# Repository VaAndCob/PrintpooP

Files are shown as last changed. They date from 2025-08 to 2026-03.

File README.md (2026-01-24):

# PrintpooP – Retro Pixel Smart Display for Bambu Lab A1

- WORK BOTH 2.4" and 2.8" Resistive Touch Screen
- Firmware version: display on the top left-most on the welcome screen
- [Version history](https://github.com/VaAndCob/PrintpooP/blob/main/CHANGELOG.md)
## Quick start, flash and go, no code needed
- [Flash Firmware Online for 2.4" and 2.8"](https://vaandcob.github.io/webpage/src/index.html)
--------------------------  
🎬[Watch on Youtube](https://www.youtube.com/playlist?list=PLtzfxJvwUDCUxc5Is3-2UeWByNE8M8oDE)

PrintpooP

Introduction: This doesn’t make my prints any better… but it does make my printer look way cooler 😂

A compact, ESP32-powered accessory designed specifically for the Bambu Lab A1, A1 Mini 3D printer. It replaces the original hotend faceplate with a custom 3D-printed enclosure (the "Box") that houses a vibrant 2.4" touchscreen display.

📡 Live Status Display
PrintpooP connects to your A1 via Wi-Fi and presents real-time print data, such as print progress, temperatures, fan speeds, and Clock. Right at the print head. This localised status view makes monitoring more intuitive and visually engaging.

🎮 8-Bit Aesthetic
All visuals are styled in charming 8-bit pixel art, giving your printer a retro personality. Animations and icons are custom-designed to blend nostalgic design with functional UX and sound effects.
Choose between two adorable themes: a playful **Kitten** or a loyal **Puppy** to accompany your printing journey!
🛠️ Easy Mounting
The enclosure is engineered to replace the Bambu Lab A1's default hotend faceplate, securing PrintpooP in a clean, integrated form factor.

HOW TO USE: 
1. Touch screen calibration will be displayed during the first run, but can also be manually entered by pressing the RESET button and releasing, then pressing the BOOT (GPIO_0) button within one second and holding it for a second.
Use a touch pen to touch all 4 corners of the screen.
2. SETUP → Wi-Fi Tab to configure Wi-Fi credentials.
3. SETUP → Printer Tab to configure the printer's IP address, access code, serial number, and time zone.
4. Enter the printer's IP address, access code, serial number, and time zone on the SETUP → Printer Tab
   
    How to get printer serial number:  https://wiki.bambulab.com/en/general/find-sn
   
    How to get printer IP address & Access Code:  https://wiki.bambulab.com/en/software/bambu-studio/failed-to-send-print-files
5. Currently, there are 4 status display pages
   
   Page 1 - PrintpooP in action (displays a cute kitten or puppy for each print stage)

      - After one minute of inactivity, trigger a "PrintpooP" swinging animation for the idle state.
 
      - After one minute of printing, initiate a "PrintpooP" swinging animation that follows the print head's movement.
   
         (This animation needs an MPU6050 gyro sensor attached as an option. The other functions work normally without this sensor.)
   
   Page 2 - Temperature / Fan speed/progress
   
   Page 3 - Print progress / remain / layer / clock
   
   Page 4 - AMS filament type and colour / current slot

Swing
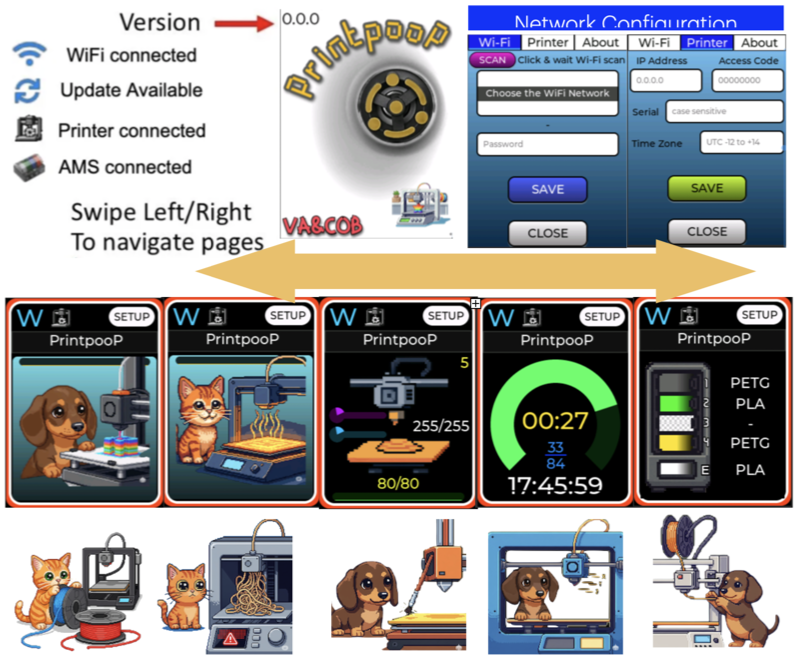
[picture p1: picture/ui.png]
Screen


## [💾 Parts assembly & soldering](https://github.com/VaAndCob/PrintpooP/tree/main/hardware)

FAQ: 
- Why is support for custom images or user-defined graphics currently unavailable?
- Why is Over-The-Air (OTA) firmware update functionality not included?
Answer: It's the hardware limitation.

---------------------------------------------------------------------------------------------------

## Part list:

- [3D Print part at MakerWorld](https://makerworld.com/en/models/1432974-PrintpooP-faceplate-kit#profileId-1490390)
- [ESP32 2.4" 240 x 320 Resistive Touch Display](https://s.click.aliexpress.com/e/_omgP1zh)
- [1W 8R 2809 Loud speaker 8 ohms 1 Watt 8R 1W 28*9*3.6MM](https://s.click.aliexpress.com/e/_oDSKVf9)
- [GY-521 MPU6050 3-Axis gyro accelerometer](https://s.click.aliexpress.com/e/_oF7jqOa)

## License

- Code: MIT License (Non-Commercial)
- 3D Designs: CC BY-NC-SA 4.0

Commercial use is strictly prohibited. For licensing inquiries, contact [Va&Cob](https://www.facebook.com/VaAndCob)

---------------------------------------------------------------------------------------------------
Buy Me a Coffee (https://www.buymeacoffee.com/vaandcob)

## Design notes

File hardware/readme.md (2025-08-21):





# [Buy->ESP32 2.4" 240 x 320 Resistive Touch Display](https://s.click.aliexpress.com/e/_omgP1zh)


# [Buy->speaker 8 ohms 1 Watt 8R 1W 28*9*3.6MM](https://s.click.aliexpress.com/e/_oDSKVf9)


# [Buy->MPU6050](https://s.click.aliexpress.com/e/_oF7jqOa)

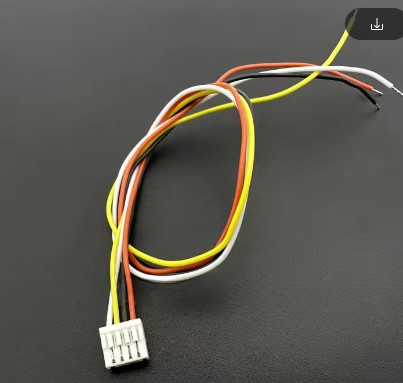
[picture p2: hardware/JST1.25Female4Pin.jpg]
JST 1.25 Female 4 Pin

# [Buy->JST 1.25 Female 4 Pin](https://s.click.aliexpress.com/e/_onDQEwb)

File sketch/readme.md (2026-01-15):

# Compiling the Source Code for PrintPooP Project

This guide provides instructions on how to set up your environment and compile the source code for the PrintPooP project using PlatformIO.

## 1. Prerequisites

* **IDE:** Visual Studio Code with the PlatformIO IDE extension.
* **Hardware:** CYD 2.4" ESP32 Dev Board (or compatible 2.8" version).

## 2. Project Setup

1.  Clone this repository to your local machine.
2.  Open the `sketch` folder in Visual Studio Code.
3.  PlatformIO should automatically detect the project and ask to install the dependencies. If not, you can install them manually using the PlatformIO sidebar.

The required libraries are listed in `platformio.ini` and will be installed automatically:
* `lovyan03/LovyanGFX`
* `lvgl/lvgl`
* `electroniccats/MPU6050`
* `knolleary/PubSubClient`
* `bblanchon/ArduinoJson`
* `fbiego/ESP32Time`

## 3. Partition Scheme

The project is configured to use a custom partition scheme `partitions/max_app_only.csv`. This is set in `platformio.ini` and no manual action is required.

## 4. Application Configuration

Before compiling, you can configure the application by editing `include/app_config.h`:

*   **Theme:** Choose between `KITTEN` and `PUPPY`.
*   **Board:** Select your CYD board model (`USE_CYD_24`, `USE_CYD_28_1`, `USE_CYD_28_2`).

```c++
//1. Select theme options
#define KITTEN 0
#define PUPPY 1

//Enter display theme you want to compile
#define THEME KITTEN //<- KITTEN or PUPPY
//-------------------------------------------

//2. Select board model options
#define USE_CYD_24_1 0 // for CYD 2.4" Variant 1
#define USE_CYD_24_2 1 // for CYD 2.4" Variant 2
#define USE_CYD_28_1 2 // for CYD 2.8" Variant 1
#define USE_CYD_28_2 3 // for CYD 2.8" Variant 2

// Enter the CYD model you want to compile
#define BOARD USE_CYD_28_1 //<- Set board here
//-------------------------------------------
```

## 5. LVGL Configuration

The `lv_conf.h` file is included in the `include` directory. The project is configured to use it automatically. No manual steps are required.

## 6. Compile and Upload

1.  Click on the PlatformIO icon in the VSCode activity bar.
2.  Under "Project Tasks", you can:
    *   **Build:** Compile the code.
    *   **Upload:** Compile and upload to your connected device.
    *   **Monitor:** Open the serial monitor.

---




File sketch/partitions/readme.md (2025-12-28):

# Adding "Max App Only (3.9MB)" Partition Scheme to Arduino IDE for ESP32

# NO NEED TO ADD A NEW PARITION ON PLATFORMIO
# This is for Arduino IDE only

This guide explains how to add a custom partition scheme to your Arduino IDE for ESP32 development, specifically one that maximizes application space to approximately 3.9MB.

**Prerequisites:**
* You have an ESP32 board support package installed in your Arduino IDE (this guide refers to version `2.0.17` as an example; paths might vary slightly for other versions).
* You have a custom partition file named `max_app_only.csv` with the following content:
    ```csv
    # Name,   Type, SubType, Offset,  Size,   Flags
    nvs,      data, nvs,     0x9000,  0x6000,
    phy_init, data, phy,     0xf000,  0x1000,
    factory,  app,  factory, 0x10000, 0x3F0000,
    ```

---

## Step 1: Modify `boards.txt` to Add the Menu Option

This step adds the new partition scheme to the Arduino IDE's "Partition Scheme" menu.

**A. Locate your `boards.txt` file:**

* **Windows:**
    ```
    C:\Users\{YourUsername}\AppData\Local\Arduino15\packages\esp32\hardware\esp32\{esp32_core_version}\boards.txt
    ```
    (Replace `{YourUsername}` and `{esp32_core_version}` e.g., `2.0.17`)

* **macOS:**
    1.  Open Finder.
    2.  Press `Shift + Command + .` (period) to show hidden files.
    3.  Navigate to:
        ```
        /Users/{YourUsername}/Library/Arduino15/packages/esp32/hardware/esp32/{esp32_core_version}/boards.txt
        ```
        (Replace `{YourUsername}` and `{esp32_core_version}` e.g., `2.0.17`)

**B. Edit `boards.txt`:**

1.  Open the `boards.txt` file in a text editor.
2.  Search for the section defining the partition schemes. It usually starts with a line similar to `esp32.menu.PartitionScheme.default=Default 4MB with spiffs ...`.
3.  Add the following lines to this section to define your new scheme:

    ```ini
    esp32.menu.PartitionScheme.max_app_only=Max App Only (3.9MB App)
    esp32.menu.PartitionScheme.max_app_only.build.partitions=max_app_only
    esp32.menu.PartitionScheme.max_app_only.upload.maximum_size=4128768
    ```
4.  Save the `boards.txt` file.

---

## Step 2: Add Your Custom Partition File (`.csv`)

This step places your custom partition layout file where the Arduino IDE can find it.

**A. Locate the `partitions` folder:**

* **Windows:**
    ```
    C:\Users\{YourUsername}\AppData\Local\Arduino15\packages\esp32\hardware\esp32\{esp32_core_version}\tools\partitions\
    ```
    (Replace `{YourUsername}` and `{esp32_core_version}`)

* **macOS:**
    ```
    /Users/{YourUsername}/Library/Arduino15/packages/esp32/hardware/esp32/{esp32_core_version}/tools/partitions/
    ```
    (Replace `{YourUsername}` and `{esp32_core_version}`)

**B. Copy your `.csv` file:**

1.  Copy your `max_app_only.csv` file into this `partitions` folder.

---

## Step 3: Clear Arduino IDE Cache (If Necessary)

Sometimes, the Arduino IDE caches board information. If the new partition scheme doesn't appear after restarting, clearing the cache might help. **Caution: This may remove other cached data.**

* **Windows:** Delete the contents of or the folder itself:
    ```
    C:\Users\{YourUsername}\AppData\Roaming\arduino-ide\
    ```
    (Replace `{YourUsername}`)

* **macOS:** Delete the contents of or the folder itself:
    ```
    /Users/{YourUsername}/Library/Application Support/Arduino-ide/
    ```
    (Replace `{YourUsername}`)

---

## Step 4: Restart Arduino IDE

Close and reopen the Arduino IDE. Your new partition scheme "Max App Only (3.9MB App)" should now be available under `Tools > Partition Scheme` when an ESP32 board is selected.

---

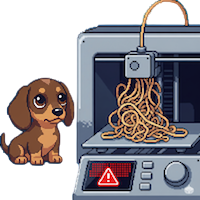
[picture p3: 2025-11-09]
squareline/assets/puppy/stage5.png

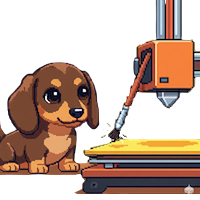
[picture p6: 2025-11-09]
squareline/assets/puppy/stage14.png

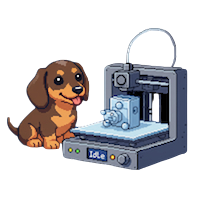
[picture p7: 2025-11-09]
squareline/assets/puppy/stage255.png

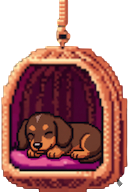
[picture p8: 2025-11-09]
squareline/assets/puppy/swing.png

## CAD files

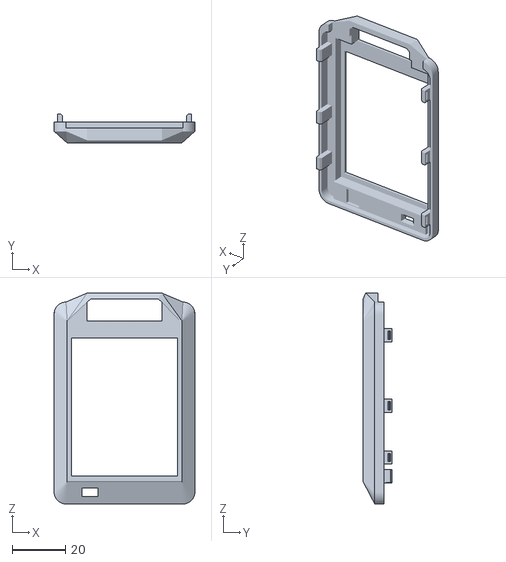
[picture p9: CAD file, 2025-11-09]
3dprint/cover.stl
53.0 x 10.9 x 79.4

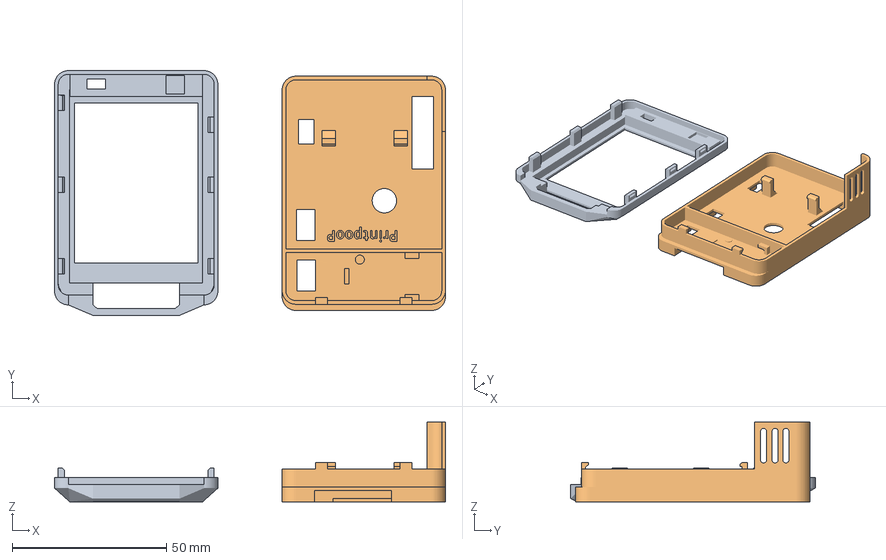
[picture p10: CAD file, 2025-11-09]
3dprint/PrintpooP.3mf
126.8 x 79.4 x 25.8 mm
cover.stl
plate.stl

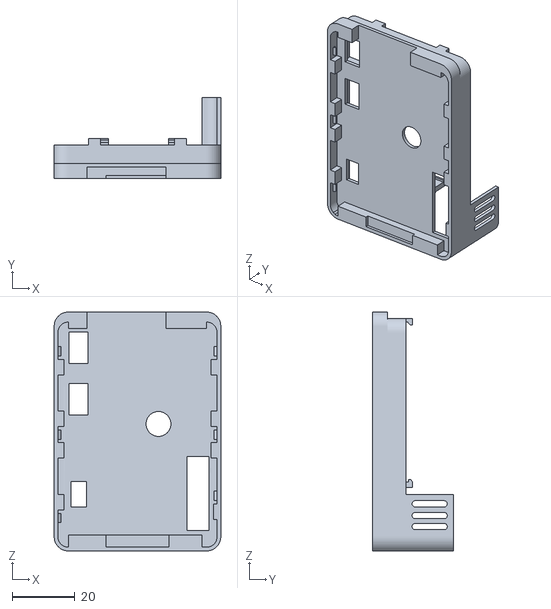
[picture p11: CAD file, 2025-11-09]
3dprint/plate.stl
53.0 x 25.8 x 76.0

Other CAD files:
3dprint/printpoop.skp
3dprint/printpoop~.skp

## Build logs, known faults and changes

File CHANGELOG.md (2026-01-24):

## Version history

### 1.7.1 (Jan 24th, 2026)
- Touch calibration not saved fixed
### 1.7.0 (Jan 15th, 2026)
- Add CYD 2.4" variant 2
- Auto screen dim Enable/Disable checkbox & Manual screen brightness setting added
### 1.6.2 (Jan 9th, 2026)
- Set screen rotation 180 degree flip button added in screen setting tab
### 1.6.1 (Dec 28th, 2025)
- Access Code can enter upper/lower case for other printer models.
### 1.6.0 (Nov 10th, 2025)
- "Kitten" and "Puppy" theme added
- Network configuration on screen
### 1.5.0 (Oct 10th, 2025)
- Replace the TFT_eSPI library to LovyanGFX library for easy configuration
- Disable brownout detection to prevent randomly reset when the ESP32 attemp to connect to WiFi implemented
- SD Card implemented for user custom image replacement in the future release.
### 1.4.6
- Add printing layer label
### 1.4.5
- The AMS current slot display is fixed.
- Temperature display fixed.
- RGB LED initialisation added
### 1.4.4 
- minor bug fixed
###1.4.3
- MQTT connection is difficult to connect, fixed.
- Primthead animation fixed
### 1.4.2 
- swing icon switch to animation when print stage change fixed
### 1.4.1 
- The AMS icon disappeared when print failed, and was fixed
### 1.4.0
- Integrate the MPU6050 gyro sensor.
- After one minute of inactivity, trigger a "PrintpooP" swinging animation for the idle state.
- After one minute of printing, initiate a "PrintpooP" swinging animation that follows the print head's movement.
https://youtu.be/ZBQTilp9lm4?si=et-ml-sNmkkoqPh6

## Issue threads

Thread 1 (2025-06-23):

[Feature Request] Hide scrolling Text bottom

zackfuchtel, 2025-06-23:
Hello,

my wife is absolute mad about your PrintpooP. Thanks for the work. But one Question, maybe you can add a FW without scrolling text at bottom? Or maybe to switch on off via setup page.

Many greetings, Andreas

VaAndCob, 2025-06-24:
Oh no! I'm so sorry to hear PrintpooP made your wife angry. What did we do wrong? 😉
.
.
That scrolling text is for future features, such as text animation.
Got a few questions:
1. Can you compile and flash with Arduino IDE, or flash with the web flasher tool?
2. I can customise the firmware without scroll text, and you can flash it yourself here. [](https://adafruit.github.io/Adafruit_WebSerial_ESPTool/). I will give you instructions on how to flash easily.

VaAndCob, 2025-06-24:
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

Oh no! I'm so sorry to hear PrintpooP made your wife angry. What did we do wrong? 😉
.
.
That scrolling text is for future features, such as text animation.
Got a few questions:

What is the CYD screen size you use 2.4" or 2.8"
Can you compile and flash with Arduino IDE, or flash with the web flasher tool?
I can customise the firmware without scroll text, and you can flash it yourself here. . I will give you instructions on how to flash easily.

zackfuchtel, 2025-06-24:
Thanks for your quick reply.

I use the 2.4 and flashed via web flasher. I tried Arduino Ide 2.x, but I guess I used the wrong lvgl (9.4.x), will try 8.x

If you could do a quick FW-bin without bottom scrolling?

VaAndCob, 2025-06-24:
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

OK please to here [Adafruit](https://adafruit.github.io/Adafruit_WebSerial_ESPTool)

and download source files (4) here
https://www.dropbox.com/scl/fo/w0j7gweyon8ax7b20xo7z/AEe7rv4Fxj-Tpw7CJ-Fm8Iw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

Closed 2025-07-23.

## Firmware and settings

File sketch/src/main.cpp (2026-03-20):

/**
 @file printpoop_app
 @author Va&Cob
 @date 2025-12-01
 @copyright Copyright (c) 2025 Va&Cob

 # Hardware: ESP32 CYD 2.4", 2.8"
 # PlatformIO
 #
 #
 # Partition scheme: Max App Only (3.9MB)
**/


//-------------------------------------------------------
#include <Arduino.h>
const String version = "1.7.1";
const String compile_date = __DATE__ " - " __TIME__;
//-------------------------------------------------------
#include "soc/rtc_cntl_reg.h" // Disable brownout problems
#include "soc/soc.h"          // Disable brownout problems

#include "LGFX_CYD.h"
#include "ui.h"
#include <ArduinoJson.h>
#include <SPI.h>
#include <lvgl.h>

// Pin configuration
#define SELECTOR_PIN 0
#define LDR_PIN 34
#define LED_RED 4
#define LED_GREEN 16
#define LED_BLUE 17
#define SPARE_PIN 35

#define TFT_WIDTH 240
#define TFT_HEIGHT 320

// SOUNDER and RTC
#include "accessory.h"
#include "mqtt.h"
#include "nes_audio.h"


LGFX tft; /* LGFX instance */

//---------------

/* Display flushing */
void my_disp_flush(lv_disp_drv_t *disp_drv, const lv_area_t *area, lv_color_t *color_p) {
  uint32_t w = (area->x2 - area->x1 + 1);
  uint32_t h = (area->y2 - area->y1 + 1);
  tft.startWrite();
  tft.setAddrWindow(area->x1, area->y1, w, h);
  tft.pushPixels((uint16_t *)&color_p->full, w * h, true);
  tft.endWrite();
  lv_disp_flush_ready(disp_drv);
}
/* Touch pad callback */
void my_touchpad_read(lv_indev_drv_t *indev_driver, lv_indev_data_t *data) {
  uint16_t touchX, touchY;
  bool touched = tft.getTouch(&touchX, &touchY);

  if (touched) {
    data->state = LV_INDEV_STATE_PR;
    data->point.x = touchX;
    data->point.y = touchY;
  } else {
    data->state = LV_INDEV_STATE_REL;
  }
}

//------------------------------------------------------
void setup() {

  WRITE_PERI_REG(RTC_CNTL_BROWN_OUT_REG, 0); // disable brownout detection
  // init communication
  Serial.begin(115200);
  delay(500);
  Serial.print(F("\n<< PrintpooP >> by Va&Cob\nVersion "));
  Serial.print(version);
  Serial.print(F(" | "));
  Serial.println(compile_date);
  //load screen flip setting
  pref.begin("config", true);
  flip = pref.getBool("flip", false);
  brightness = pref.getChar("brightness", 128);
  auto_dim = pref.getBool("autodim", true);
  pref.end();

// Pin configuration by board type
#if (BOARD == USE_CYD_24_1 || BOARD == USE_CYD_24_2)
if (flip) rotation = 6; else rotation = 4;//rotation = 4; // 6 rotate 180
#define SDA_PIN 21
#define SCL_PIN 22
  GAIN = 5.0; // speaker volume
  setVersion(version, "printpoop24_kitten_manifest.json");
#elif BOARD == USE_CYD_28_1
if (flip) rotation = 2; else rotation = 0;//rotation = 0; //or 2 rotate 180
#define SDA_PIN 27
#define SCL_PIN 22
  GAIN = 2.0; // speaker volume (recommend connect AMP IC pin 4 and 5 with R 1K ohm)
  setVersion(version, "printpoop28_1_kitten_manifest.json");
#elif BOARD == USE_CYD_28_2
if (flip) rotation = 6; else rotation = 4;//rotation = 4;// or 6 rotate 180
#define SDA_PIN 27
#define SCL_PIN 22
  GAIN = 2.0; // speaker volume
  setVersion(version, "printpoop28_2_kitten_manifest.json");
#endif

  // pin configuration
  analogSetAttenuation(ADC_0db);       // 0dB(1.0 ครั้ง) 0~800mV   for LDR
  pinMode(LDR_PIN, ANALOG);            // ldr analog input read brightness
  pinMode(SELECTOR_PIN, INPUT_PULLUP); // button
  pinMode(LED_RED, OUTPUT);
  pinMode(LED_GREEN, OUTPUT);
  pinMode(LED_BLUE, OUTPUT);
  digitalWrite(LED_RED, HIGH);
  digitalWrite(LED_GREEN, HIGH);
  digitalWrite(LED_BLUE, HIGH);

  mpu_init(SDA_PIN, SCL_PIN); // init MPU6050

  // init TFT
  tft.begin();
  tft.setRotation(rotation); // Portrait
  tft.setBrightness(128);

  // screen calibration
  uint16_t calData[8];
  pref.begin("touch", false);
  if (digitalRead(SELECTOR_PIN) == LOW) {
    tft.calibrateTouch(calData, TFT_WHITE, TFT_BLACK, 15);
    pref.putBytes("calData", calData, sizeof(calData));
    Serial.println("Touch calibration saved.");
  } else {
    if (pref.getBytes("calData", calData, sizeof(calData)) == sizeof(calData)) {
      tft.setTouchCalibrate(calData);
      Serial.println("Touch calibration loaded.");
    }
  }
  pref.end();

  lv_init();// init lvgl

  // LVGL display buffers
  static lv_disp_draw_buf_t draw_buf;
  // Allocate buffer for 1/6 of the screen size
  static lv_color_t buf1[TFT_WIDTH * TFT_HEIGHT / 6];
  static lv_color_t buf2[TFT_WIDTH * TFT_HEIGHT / 6];
  lv_disp_draw_buf_init(&draw_buf, buf1, buf2, TFT_WIDTH * TFT_HEIGHT / 6);

  // Register display driver
  static lv_disp_drv_t disp_drv;
  lv_disp_drv_init(&disp_drv);
  disp_drv.hor_res = TFT_WIDTH;
  disp_drv.ver_res = TFT_HEIGHT;
  disp_drv.flush_cb = my_disp_flush;
  disp_drv.draw_buf = &draw_buf;
  lv_disp_drv_register(&disp_drv);

  // Touch input driver
  static lv_indev_drv_t indev_drv;
  lv_indev_drv_init(&indev_drv);
  indev_drv.type = LV_INDEV_TYPE_POINTER;
  indev_drv.read_cb = my_touchpad_read;
  lv_indev_drv_register(&indev_drv);

  ui_init();
  
  //brightness
  if (auto_dim) {
    lv_obj_add_state(ui_setup_checkbox_autodim, LV_STATE_CHECKED);
    lv_obj_add_flag(ui_setup_slider_brightness, LV_OBJ_FLAG_HIDDEN);
  } else {
    lv_obj_clear_state(ui_setup_checkbox_autodim, LV_STATE_CHECKED);
    lv_slider_set_value(ui_setup_slider_brightness, brightness, LV_ANIM_ON);
    lv_obj_clear_flag(ui_setup_slider_brightness, LV_OBJ_FLAG_HIDDEN);
    tft.setBrightness(brightness);
  }

  // lv_label_set_text(ui_status_label_printstage,"Idle"); //test swing
    Serial.printf(
        "Heap free: %u | Largest block: %u\n",
        heap_caps_get_free_size(MALLOC_CAP_8BIT),
        heap_caps_get_largest_free_block(MALLOC_CAP_8BIT)
    );
}

//------------------------------------------------------
void loop() {

  autoDim();
  wifi_status();
  mqtt_handler();
  update_clock();
  idle_animation();
  print_animation();

  lv_task_handler();
}
//------------------------------------------------------

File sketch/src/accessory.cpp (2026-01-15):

// Helper functions

#include "accessory.h"
#include "ui.h"
#include <stdio.h>
#include <HTTPClient.h>
#include <ArduinoJson.h>
#include <Wire.h>
#include <MPU6050.h>
//======================== RTC =================================
#include <ESP32Time.h>  //user ESP32 Internal Realtime Clock
ESP32Time rtc;          //offset GMT+7
//mytime currentTime;

bool flip = false;
uint8_t rotation = 0;

String TZoffset = "0";
#define UTC_OFFSET_DST 0
#define NTP_SERVER "pool.ntp.org"

void initRTC() {

  // Convert GMT string to int and validate
  int gmtOffset = TZoffset.toInt();
  if (gmtOffset < -12 || gmtOffset > 14) {
    Serial.println(F("Invalid GMT offset, defaulting to 0"));
    gmtOffset = 0;
  }

  int32_t UTC_OFFSET = 3600 * TZoffset.toInt();
  configTime(UTC_OFFSET, UTC_OFFSET_DST, NTP_SERVER);
  delay(100);
  //---------set with NTP---------------
  struct tm timeinfo;
  if (getLocalTime(&timeinfo)) {
    rtc.setTimeStruct(timeinfo);
    Serial.println(&timeinfo, "%A, %B %d %Y %H:%M:%S");
  } else {
    Serial.print(F("Unable to setup RTC!\n"));
  }
}

//get current time
String get_current_time() {

  struct tm timeinfo = rtc.getTimeStruct();  //get time from esp32 RTC
#ifdef SERIAL_DEBUG
  Serial.println(&timeinfo, "%A, %B %d %Y %H:%M:%S");  //  (tm struct) Sunday, January 17 2021 07:24:38
#endif
  /*
//Serial.println(&timeinfo, "%H:%M:%S - %d/%m/%Y   %Z");
  currentTime.h = timeinfo.tm_hour;
  currentTime.m = timeinfo.tm_min;
  currentTime.s = timeinfo.tm_sec; */
  char buffer[16];  // Enough for "HH:MM:SS\0"
  strftime(buffer, sizeof(buffer), "%H:%M:%S", &timeinfo);
  return String(buffer);
}


/*------------ SOUND EFFECT ----------*/
#define speakerChannel 2
#define SPEAKER_PIN 26  //speaker

void initSpeaker() {
  pinMode(SPEAKER_PIN, OUTPUT);                //speaker
  ledcSetup(speakerChannel, 1500, 10);         //speaker 10 bit
  ledcAttachPin(SPEAKER_PIN, speakerChannel);  //attach speaker
}

void beepbeep() {  //2 shot beep
  initSpeaker();
  ledcWriteTone(speakerChannel, 2000);
  delay(50);
  ledcWriteTone(speakerChannel, 0);
  delay(50);
  ledcWriteTone(speakerChannel, 2000);
  delay(50);
  ledcWriteTone(speakerChannel, 0);
}
void beep() {
  initSpeaker();
  ledcWriteTone(speakerChannel, 2000);
  delay(500);
  ledcWriteTone(speakerChannel, 0);
}
void clickSound() {
  initSpeaker();
  ledcWriteTone(speakerChannel, 5000);
  delay(5);
  ledcWriteTone(speakerChannel, 0);
}

//-----------  auto dim backlight function ------------
bool auto_dim = true;
uint8_t brightness = 128;
#define LDR_PIN 34  //LDR sensor
#define backlightChannel 0
static uint8_t low_count = 0;
static uint8_t high_count = 0;
static bool dim = false;                   //back light dim flag
static const uint16_t LIGHT_LEVEL = 1500;  //backlight control by light level Higher = darker light

void autoDim() {
  if (!auto_dim) return;
  int light = analogRead(LDR_PIN);  //read light
  // Serial.printf("LDR: %d\n",light);
  if (light > LIGHT_LEVEL) {  //low light
    low_count++;
    if (low_count > 10) {
      low_count = 10;  //low amb light 10 times count
      if (!dim) {
         tft.setBrightness(50);  //dim light
        dim = true;
      }  //if !dim
    }    //if low_count
    high_count = 0;

  } else {
    high_count++;
    if (high_count > 10) {
      high_count = 10;  //high amb light 10 times count
      if (dim) {
        tft.setBrightness(200);
        dim = false;
      }  //if dim
    }    //if high_count
    low_count = 0;
  }  //if light > lightlevel
}  //autodim

void init_TFT_BL(uint8_t BL_PIN) {
  pinMode(BL_PIN, OUTPUT);
  ledcSetup(backlightChannel, 12000, 8);
  ledcAttachPin(BL_PIN, backlightChannel);
  ledcWrite(backlightChannel, 127);  //set screen brightness
}

//------------ Check new firmware update from web flasher --------------------
/*manifest.json
{
    "name": "PrintpooP",
    "version": "1.3.2",
    "new_install_prompt_erase": true, 
    "new_install_improv_wait_time": 0,
    "builds": [
      {
        "chipFamily": "ESP32",
        "parts": [
          { "path": "bootloader.bin", "offset": 4096 },
          { "path": "partitions.bin", "offset": 32768},
          { "path": "boot_app0.bin", "offset": 57344 },
          { "path": "printpoop24_app.ino.bin", "offset": 65536 }
        ]
      }
    ]
}*/

String current_version = "";    // current firmware version
bool firmware_checked = false;  //check firmware flag
String firmware_manifest = "";
//------------------------------------------------
void setVersion(const String ver, String manifest) {
  current_version = ver;
  firmware_manifest = manifest;
}

//function return firmware version to integer number
int versionToNumber(String version) {
  int major = version.substring(0, version.indexOf('.')).toInt();
  version = version.substring(version.indexOf('.') + 1);
  int minor = version.substring(0, version.indexOf('.')).toInt();
  version = version.substring(version.indexOf('.') + 1);
  int patch = version.toInt();
  // Combine the parts into a single integer for comparison
  return major * 10000 + minor * 100 + patch;
}
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

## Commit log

2025-10-12 version 1.5.0
    - Replace TFT_eSPI with LovyanGFX
    - Disable brownout detection implemented
    (fixed CYD randomly restart when start the WiFi connection)
    - SD Card implemented
    (prepare for custom picture replacement)
    [LGFX_CYD.h, accessory.cpp]
2025-10-12 changelog update
    ### 1.5.0 (Oct 10th, 2025)
    - Replace TFT_eSPI library to LovyanGFX library for easy configuration
    - Disable brownout detection to prevent randomly reset when the ESP32 attemp to connect to WiFi implemented
    - SD Card implemented for user custom image replacement in the future release.
2025-11-06 CYD 2.8" Vairante 2 firmware fixed
    [LGFX_CYD.h]
2025-11-06 CYD_28_2 configuration edited
    fixed wrong display for ESP32 CYD 2.8" variant 2
    [LGFX_CYD.h]
2025-11-09 version 1.6.0
    [max_app_only.csv]
2025-11-09 gitignore update
    [PrintpooP.3mf, cover.stl, plate.stl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]
2025-12-07 Update platformio.ini
    lock espressif32 version to v6.12.0
    (esp32 core 2.0.17)
2025-12-28 version 1.6.1 updated
    - Access Code can enter upper/lower case for other printer models.
2026-01-09 version 1.6.2 update
    Set screen rotation 180 degree flip button added in screen setting tab
    [accessory.cpp, main.cpp, ui_events.cpp]
